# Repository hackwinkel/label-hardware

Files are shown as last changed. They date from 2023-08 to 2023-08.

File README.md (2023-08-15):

# label-hardware

The "label" is a cheap badge with a PADAUK PFS154-S16 microcontroller, 40 leds and IR transmitter & receiver for inter-badge communications.
The software/hardware *may* also work with a PMS150C-S16 and pin compatible controllers from other manufacturers (e.g. Nyquest tech), but this is untested

This hardware goes with the software described here: https://github.com/hackwinkel/label-software

## Background

This badge was originally designed for SMD hotplate soldering workshops at TBD (https://tbd.camp/) and later used for workshops at bornhack 2023 () and private workshops

According to internet rule 663829, "Every hacker conference shall have a badge". Being hackers, of course, leads to hypotheses 1-3:
"1: Any hacker conference badge will be overly complex",
"2: Any hacker conference badge will be released with unfinished software" and
"3: Any hacker conference  badge will function poorly for its namesake purpose".
This badge disproves these 3 hypotheses.

## What is in this repository

0) This README
1) a LICENSE file
2) A directory with KiCAD 5 source files
3) A directory with PCB fabrication (Gerber) files produced from these source files
4) A ZIP file containing the Gerber files for PCB fabrication.
5) A director with stencil fabrication (Gerber) files, with 4 copies of the stencil (will fit on a single laser-cut stencil)
6) A ZIP file containing the Gerber files for stencil fabrication.
7) A parts list

If you only want to produce PCBs, you should be able to upload the PCB_fabrication.zip file to your PCB board house directly.
If you want to produce a single stencil, you can use  the PCB_fabrication.zip file - yoor PCB board house will extract the right file from this.
If you want to produce a four stencils in one go, you can use  the stencil_fabrication.zip file.

As the board only contains SMD components on the front side, you have to specify that the PCB board house should make a stencil from the "front paste" Gerber file only

## Reprogramming in-circuit

Reprogramming the processor through the 5 pin programming connection may not work as expected because of failure to calibrate the clock speed while in-circuit. You CAN reprogram the badge without clock-speed calibration by using easypdkprog with the --nocalibrate option.

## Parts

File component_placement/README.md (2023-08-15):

# Component placement
The badge contains 56 SMD and 2 (or 3) through-hole components. Regardless of your fabrication method (solder paste & reflowing OR manual soldering) it is best to start with the SMD components, and place these in a specific order.

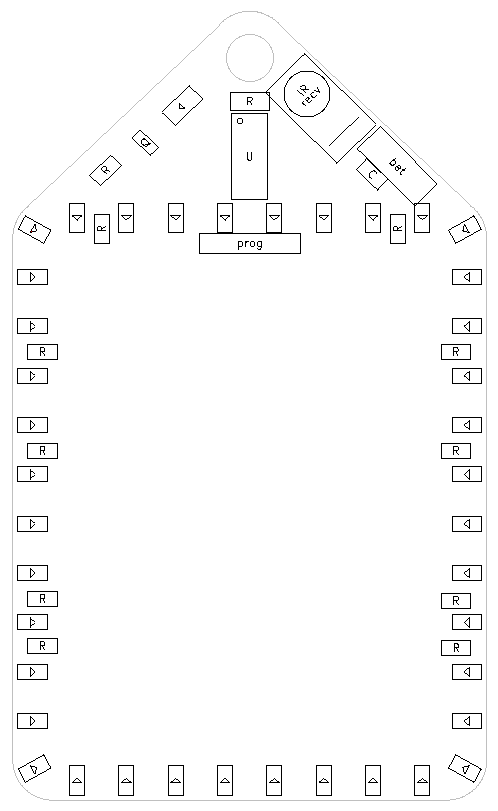
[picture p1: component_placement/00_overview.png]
overview


Step 1: Place the LEDs in the correct orientation. Use a mirror if necessary.

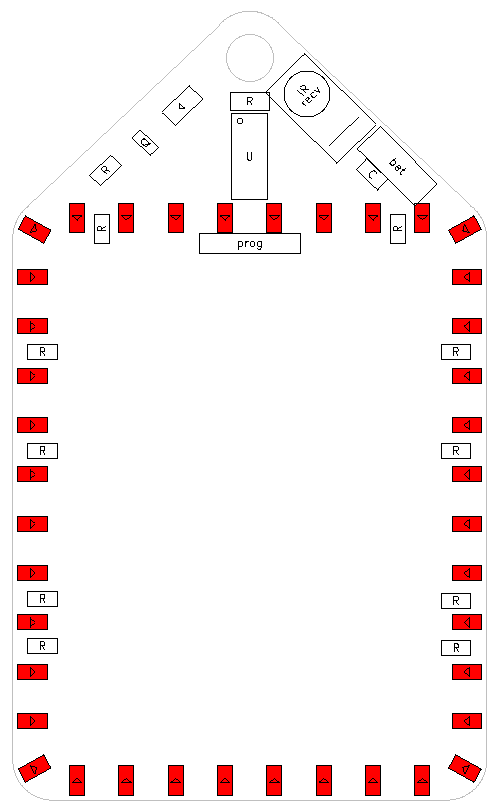
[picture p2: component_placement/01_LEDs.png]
LEDs


Step 2: Place the 220 Ohm resistors. Orientation is not important, but place them with the black side up.

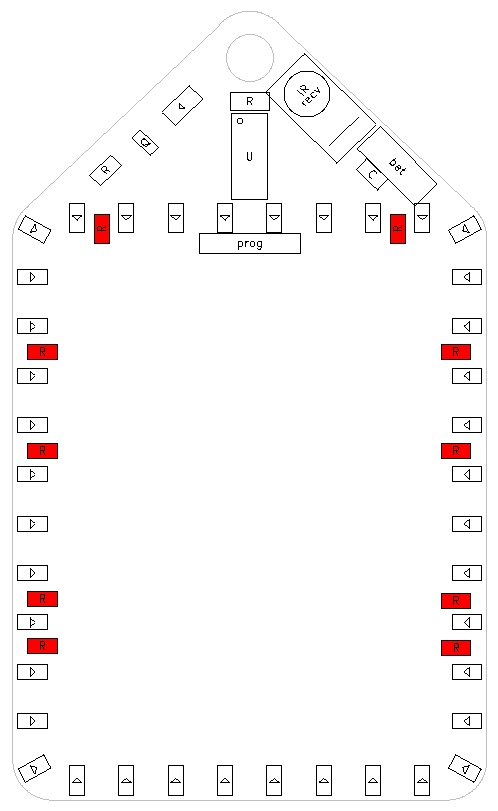
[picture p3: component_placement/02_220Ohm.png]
220 Ohm


Step 3: Place the 1kOhm gate protection resistor. Orientation is not important, but place it with the black side up.

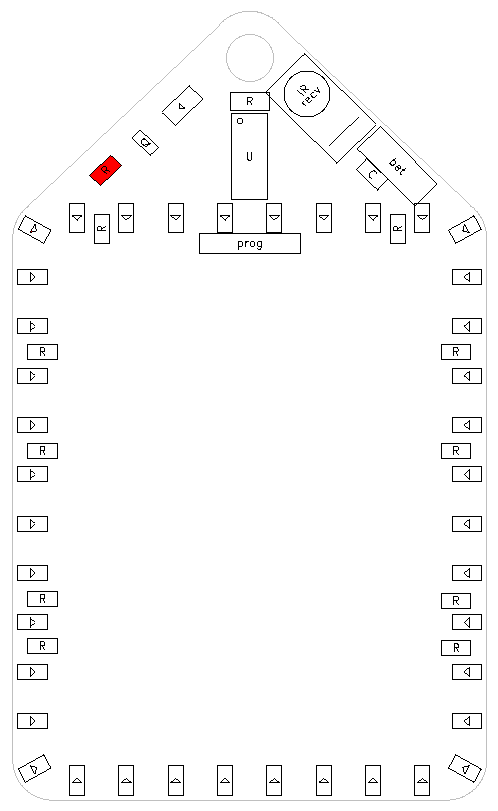
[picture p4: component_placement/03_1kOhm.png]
1k Ohm


Step 4: Place the mosfet. The mosfet will fit only in one orientation.

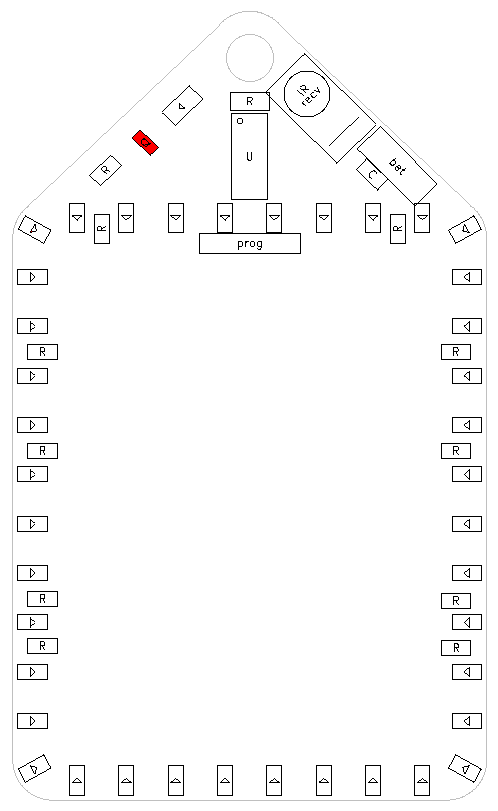
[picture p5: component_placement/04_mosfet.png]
mosfet


Step 5: Place the IR LED in the correct orientation.

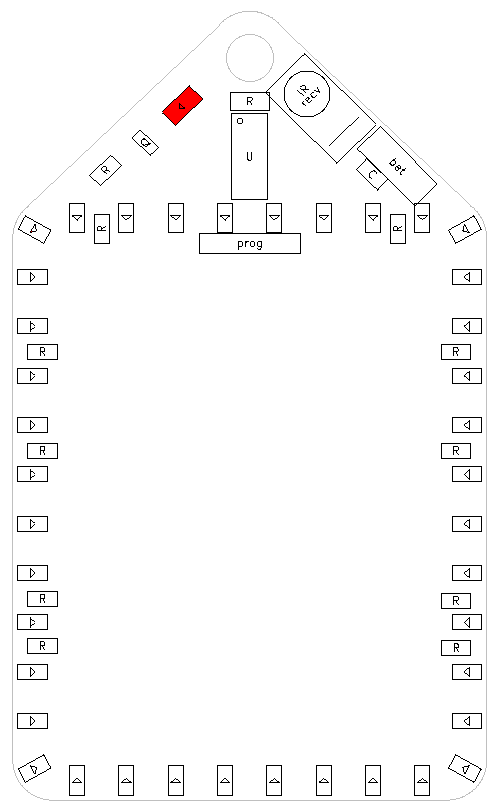
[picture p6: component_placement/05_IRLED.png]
IR LED


Step 6: Place the (large) 22 Ohm protection resistor. Orientation is not important, but place it with the black side up.

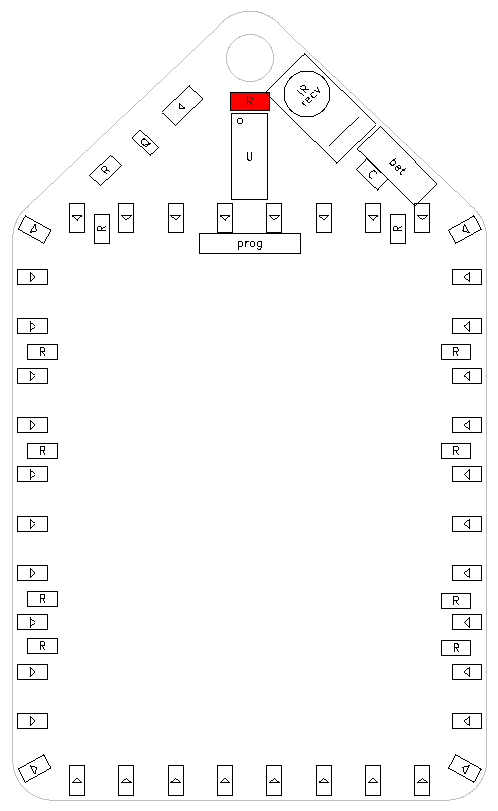
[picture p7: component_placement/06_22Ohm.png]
22 Ohm


Step 7: Place the 100nF capacitor. Orientation is not important.

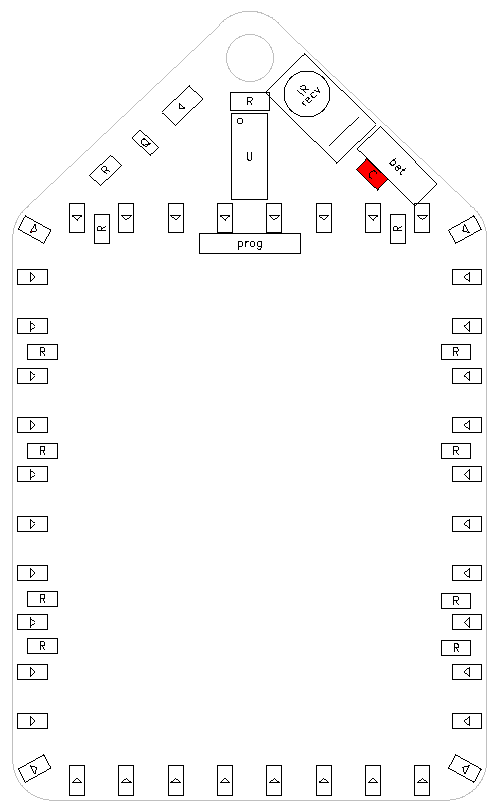
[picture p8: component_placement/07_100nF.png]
100 nF


Step 8: Place the PADAUK microprocessor in the correct orientation

PADAUK

If you are doing reflow soldering, you now need to do the reflowing - before mounting the through-hole components.

Step 9: Bend the legs of the IR receiver 90 degrees so that the receiver lens will look UP from the PCB and mount it.

IR receiver

Step 10: fix the battery holder to the other side of the PCB using double-sided tape. Shorten the wires a bit, and solder them onto the battery connection pads (square pad = minus).

battery

Step 11: (if wanted) solder a 5 pin pin header into the programming connection. Note that In Circuit Reprogramming can be done, but clock speed calibration may not work. If this is the case, you need to run easypdkprog with the --nocalibrate option.

programmer connection

Step 12: insert batteries and enjoy your badge!

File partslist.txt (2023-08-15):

Each badge contains the following components (with LCSC numbers where available)

note: GENERIC parts can be freely interchanged with other parts of the same value
note: it may be cheaper to order GENERIC parts from AliExpress - shipping of complete rolls of parts is generally cheaper via AliExpress than through LCSC

1 * badge PCB - order from your favorite PCB board house

40 * generic 0805 SMD leds - e.g. LCSC# C965815

10 * generic 0805 220 Ohm resistor - e.g. LCSC# C2933537

1 * generic 0805 1k Ohm resistor - e.g. LCSC# C3017842

1 * generic 0805 100nF capacitor - e.g. LCSC# C476766

1 * generic 1206 22 Ohm resistor - e.g. LCSC# C2907457

1 * ZSIRM-Z5PK81 IR receiver - LCSC# C5337487
	note: various pin compatibe alternatives exist
	
1 * XL-2835IR-T202 IR transmitter - LCSC# C5221243 
	note: various pin compatibe alternatives exist

1 * PFS154-S16 - LCSC# C317613

1 * generic 5 pin 2.54mm pitch pin header - if you want to try in-circuit reprogramming

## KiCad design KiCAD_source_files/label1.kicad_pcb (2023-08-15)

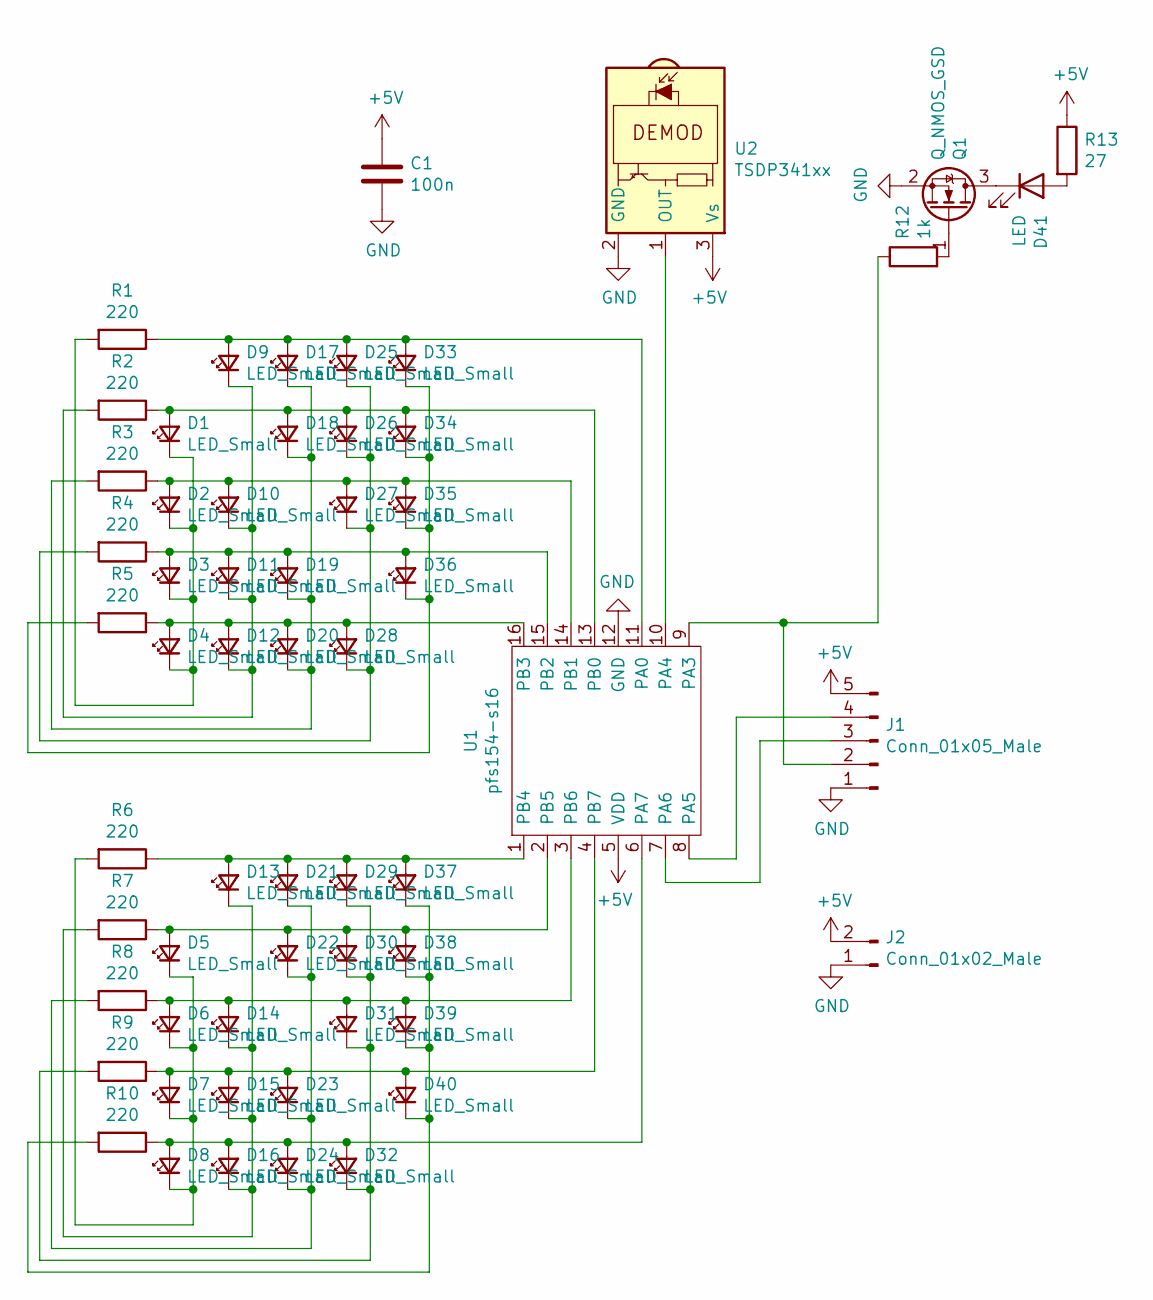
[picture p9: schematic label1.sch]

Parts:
C1: 100n; C_0805
D1, D2, D3, D4, D5, D6, D7, D8, D9, D10, D11, D12, D13, D14, D15, D16, D17, D18, D19, D20, D21, D22, D23, D24, D25, D26, D27, D28, D29, D30, D31, D32, D33, D34, D35, D36, D37, D38, D39, D40: LED_Small; D_0805
D41: LED; LED_2835
J1: Conn_01x05_Male; PinHeader_1x05
J2: Conn_01x02_Male; battcon
Q1: Q_NMOS_GSD; SOT-23
R1, R2, R3, R4, R5, R6, R7, R8, R9, R10: 220; R_0805
R12: 1k; R_0805
R13: 27; R_1206
U1: pfs154-s16; SOP-16
U2: TSDP341xx; IR_receiver

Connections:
+5V: C1.1, J1.5, J2.2, R13.1, U1.5 (VDD), U2.3 (Vs)
GND: C1.2, J1.1, J2.1, Q1.2 (S), U1.12 (GND), U2.2 (GND)
unnamed: D1.1 (K), D2.1 (K), D3.1 (K), D4.1 (K), R1.2
unnamed: D1.2 (A), D18.2 (A), D26.2 (A), D34.2 (A), R2.1, U1.13 (PB0)
unnamed: D5.1 (K), D6.1 (K), D7.1 (K), D8.1 (K), R6.2
unnamed: D9.1 (K), D10.1 (K), D11.1 (K), D12.1 (K), R2.2
unnamed: D2.2 (A), D10.2 (A), D27.2 (A), D35.2 (A), R3.1, U1.14 (PB1)
unnamed: D3.2 (A), D11.2 (A), D19.2 (A), D36.2 (A), R4.1, U1.15 (PB2)
unnamed: D4.2 (A), D12.2 (A), D20.2 (A), D28.2 (A), R5.1, U1.16 (PB3)
unnamed: D13.1 (K), D14.1 (K), D15.1 (K), D16.1 (K), R7.2
unnamed: D13.2 (A), D21.2 (A), D29.2 (A), D37.2 (A), R6.1, U1.1 (PB4)
unnamed: D6.2 (A), D14.2 (A), D31.2 (A), D39.2 (A), R8.1, U1.3 (PB6)
unnamed: D7.2 (A), D15.2 (A), D23.2 (A), D40.2 (A), R9.1, U1.4 (PB7)
unnamed: D8.2 (A), D16.2 (A), D24.2 (A), D32.2 (A), R10.1, U1.6 (PA7)
unnamed: D17.1 (K), D18.1 (K), D19.1 (K), D20.1 (K), R3.2
unnamed: D9.2 (A), D17.2 (A), D25.2 (A), D33.2 (A), R1.1, U1.11 (PA0)
unnamed: D21.1 (K), D22.1 (K), D23.1 (K), D24.1 (K), R8.2
unnamed: D5.2 (A), D22.2 (A), D30.2 (A), D38.2 (A), R7.1, U1.2 (PB5)
unnamed: D25.1 (K), D26.1 (K), D27.1 (K), D28.1 (K), R4.2
unnamed: D29.1 (K), D30.1 (K), D31.1 (K), D32.1 (K), R9.2
unnamed: D33.1 (K), D34.1 (K), D35.1 (K), D36.1 (K), R5.2
unnamed: D37.1 (K), D38.1 (K), D39.1 (K), D40.1 (K), R10.2
unnamed: D41.1 (K), Q1.3 (D)
unnamed: D41.2 (A), R13.2
unnamed: J1.2, R12.1, U1.9 (PA3)
unnamed: J1.3, U1.7 (PA6)
unnamed: J1.4, U1.8 (PA5)
unnamed: Q1.1 (G), R12.2
unnamed: U1.10 (PA4), U2.1 (OUT)

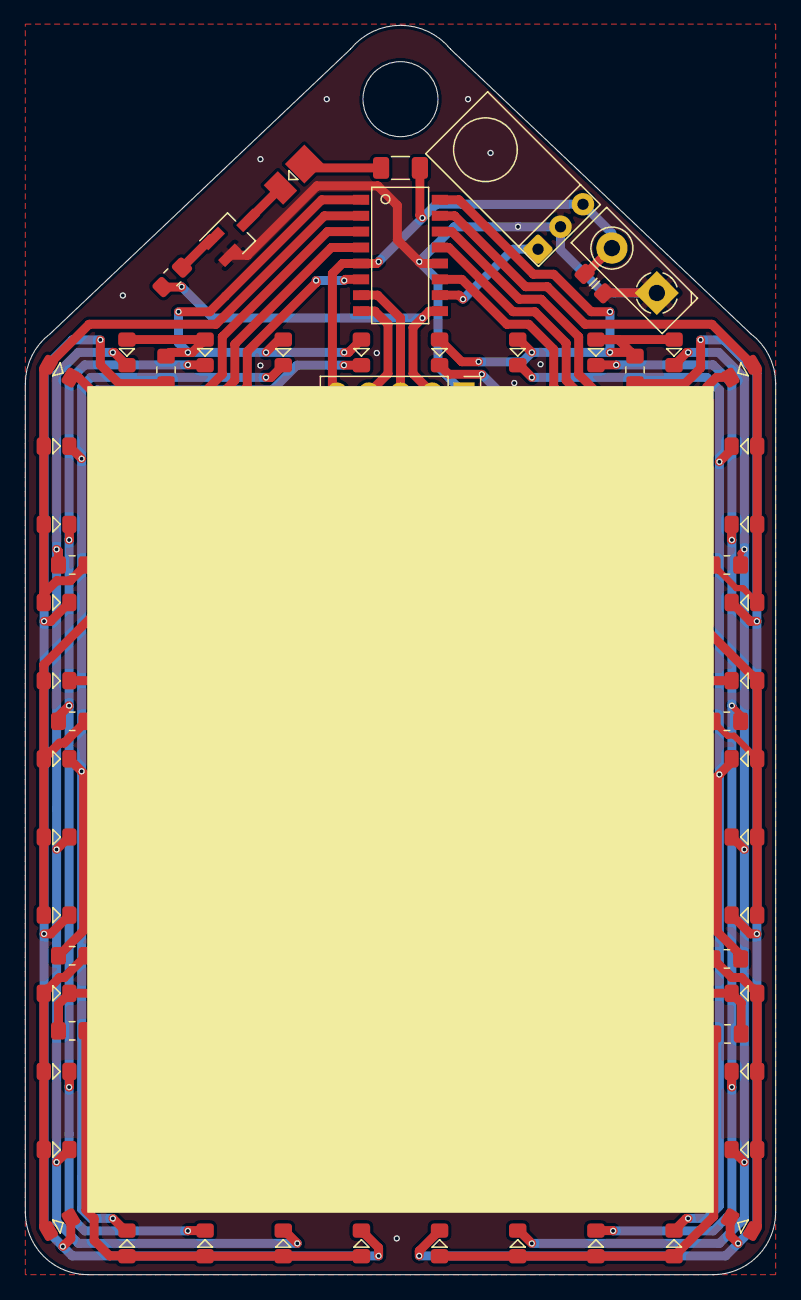
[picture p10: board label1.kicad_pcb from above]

Board: 2 copper layers, 60.0 x 99.9 mm, 59 parts (0 on the bottom side), 29 nets.

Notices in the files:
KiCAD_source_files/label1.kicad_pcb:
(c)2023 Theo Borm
